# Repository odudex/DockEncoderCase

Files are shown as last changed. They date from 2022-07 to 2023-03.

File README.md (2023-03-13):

# Maix Dock Enclosure for Krux Signer
Case for Maix Dock board with camera, display and a rotary encoder, intended to be used with Krux Signer

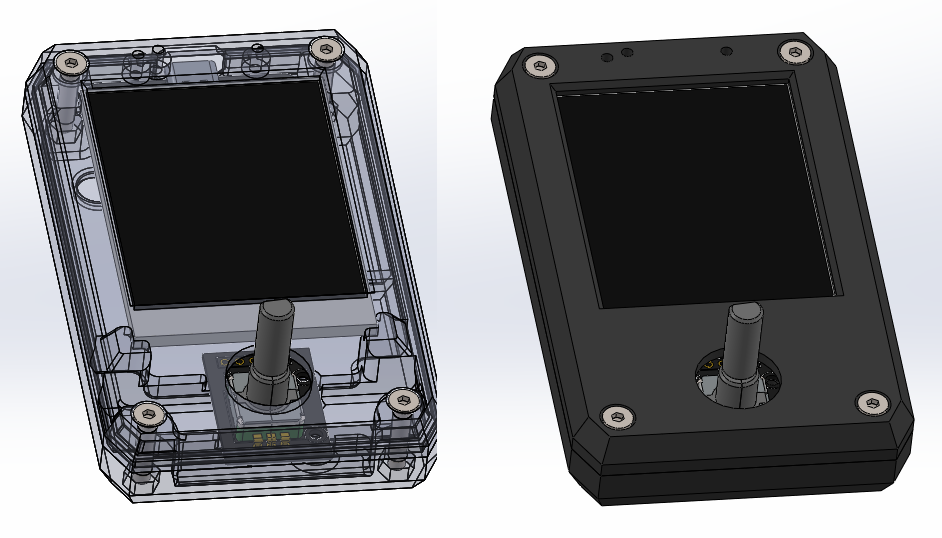
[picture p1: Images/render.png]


Materials for building a Krux 
- Printed parts
- Maix Dock with display and camera
- Rotary Encoder Ky-040
- 4 Screws for plastics (~2.5 mm) x 4mm 
- 4 M3 nuts
- 4 M3 x 16mm Allen flat screws
- 5 ~8cm thin wires
- 1cm x 1cm x 1mm thieck adesive foam

Instructions

Print the stl files, clean and test fittings.

Solder wires between board and rotary encoder.

```
Encoder - Maix Dock
   GND <->  GND
     + <->  3V3
    SW <-> Pin 9
    DT <-> Pin 10
   CLK <-> Pin 11
```

Use the foam as a flexible spacer between camera and board. It will keep the camera slightly pressed against the enclosure. Carefully place the board, with camera on place and use 2 plastic screws in diagonal to fix the board and camera to the back enclosure.

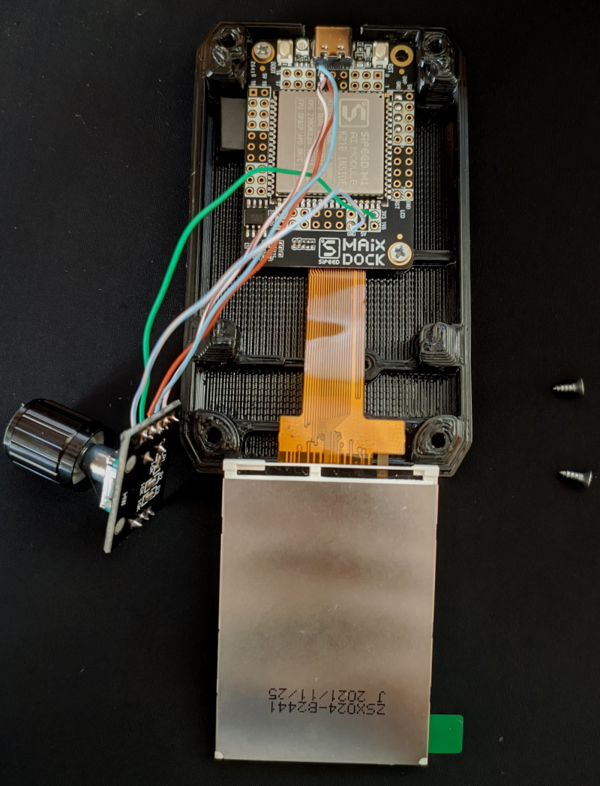
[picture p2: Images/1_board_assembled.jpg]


Put wires in place and use the other 2 plastic screws to mount the encoder.

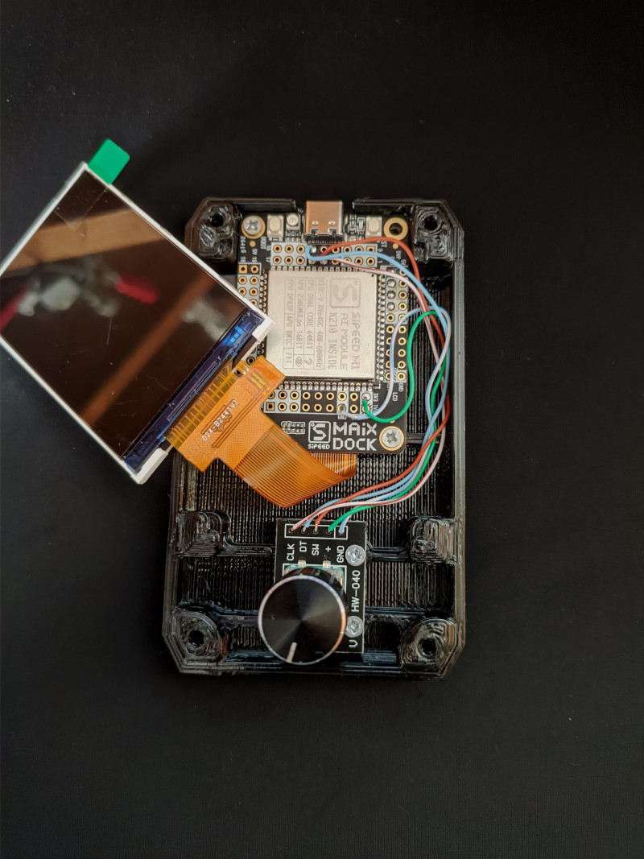
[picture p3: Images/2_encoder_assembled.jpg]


Put the display in place

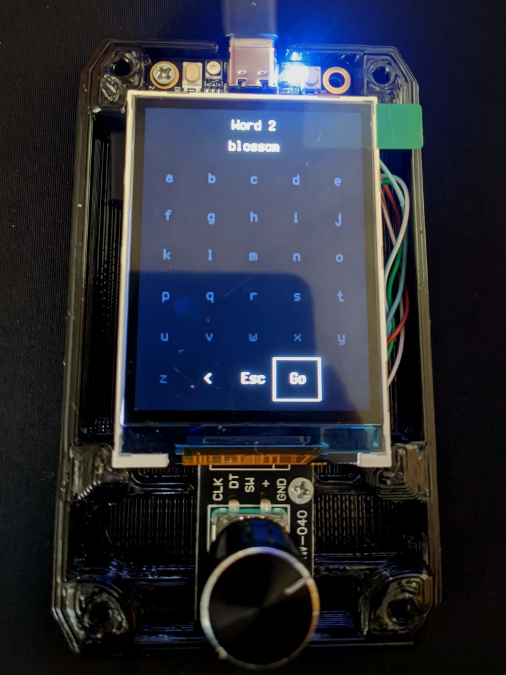
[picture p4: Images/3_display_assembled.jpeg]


Put the front enclosure in place and fix it with M3 screws and Nuts

Flash the firmware and enjoy!

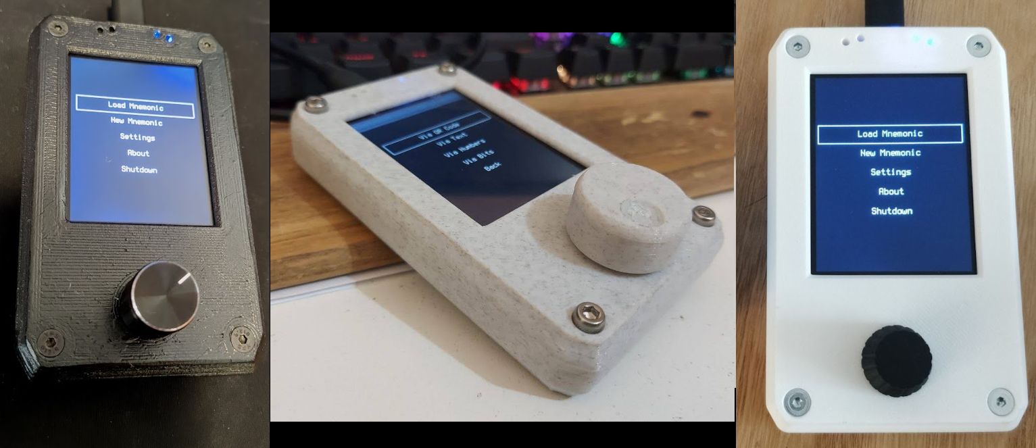
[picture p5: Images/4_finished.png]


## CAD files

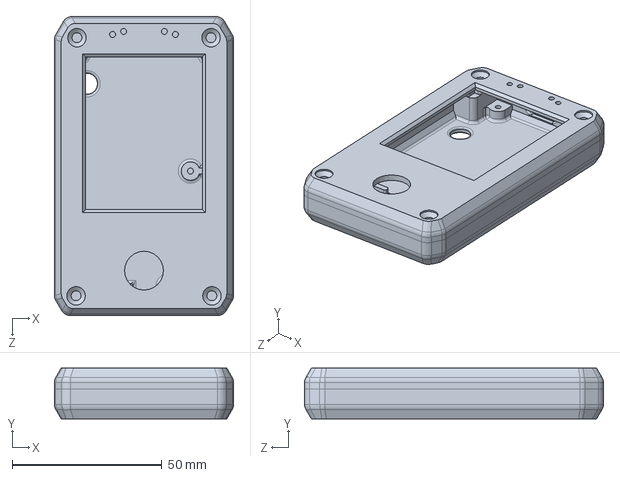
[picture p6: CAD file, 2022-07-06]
SolidWorks/Enclosure.SLDPRT
60.0 x 17.0 x 100.0 mm

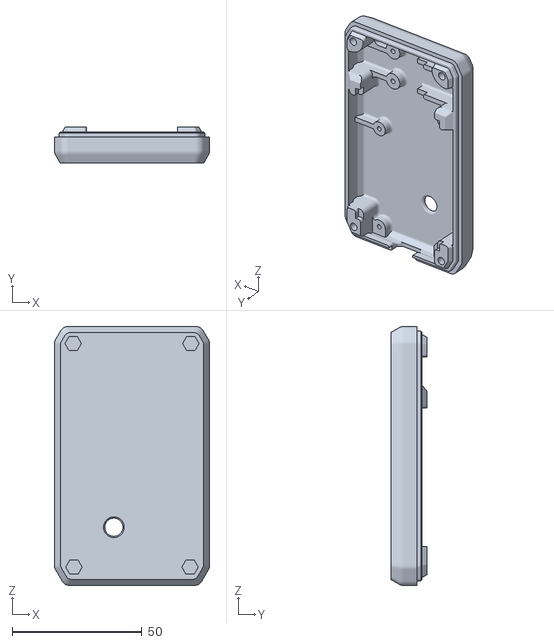
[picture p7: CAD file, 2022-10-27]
STL/Enclosure_back_short_camera.STL
60.0 x 14.0 x 100.0

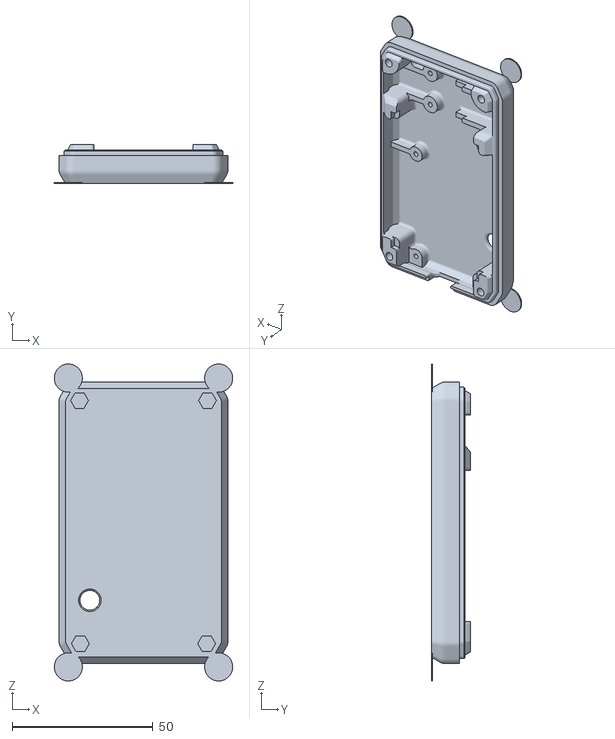
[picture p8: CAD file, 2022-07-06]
STL/Enclosure_back.STL
63.4 x 14.0 x 112.5

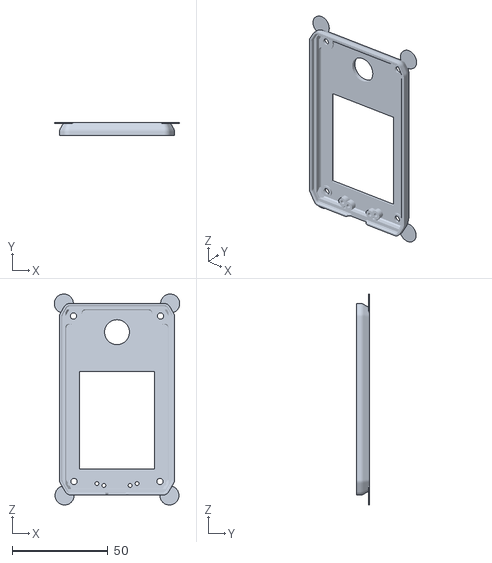
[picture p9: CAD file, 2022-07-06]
STL/Enclosure_front.STL
65.5 x 7.00 x 110.1

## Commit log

2022-07-06 Increased lip and groove tolerances
    [Enclosure.SLDPRT, Enclosure_back.STL, Enclosure_front.STL]
2022-10-27 Add version compatible with short cable camera sensor
    [Enclosure_back_short_camera.STL]
